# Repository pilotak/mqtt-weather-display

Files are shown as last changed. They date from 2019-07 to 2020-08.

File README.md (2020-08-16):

# MQTT weather display



Simple weather and time display, ready to be controlled from MQTT, based on ESP8266, ILI9341 and DS3231. Icon names are based on clientraw format weather station.

**Custom component from clientraw weather station for HomeAssistant can be found [here](https://github.com/pilotak/homeassistant-clientraw)**

HomeAssistant config:

```yaml
# automations.yaml
- alias: Forecast change
  initial_state: True
  trigger:
    platform: state
    entity_id: sensor.clientraw_symbol
  condition:
    condition: template
    value_template: '{{ trigger.from_state.state != trigger.to_state.state }}'
  action:
    service: mqtt.publish
    data_template:
      topic: "mqtt-weather-display/forecast"
      qos: 1
      retain: true
      payload: >
        {%- set symbol = states.sensor.clientraw_symbol.state -%}
        {%- if symbol is not none and symbol != "unavailable" -%}
          {{ symbol }}
        {%- endif -%}

- alias: Outside temp change
  initial_state: True
  trigger:
    platform: state
    entity_id: sensor.clientraw_temperature
  condition:
    condition: template
    value_template: '{{ trigger.from_state.state != trigger.to_state.state }}'
  action:
    service: mqtt.publish
    data_template:
      topic: "mqtt-weather-display/out-temp"
      qos: 1
      retain: true
      payload: >
        {%- set out_temp = states.sensor.clientraw_temperature.state -%}
        {%- if out_temp is not none and out_temp != "unavailable" -%}
          {{ out_temp }}
        {%- endif -%}

- alias: Inside temp change
  initial_state: True
  trigger:
    platform: state
    entity_id: sensor.myslipotemp_1_0
  condition:
    condition: template
    value_template: '{{ trigger.from_state.state != trigger.to_state.state }}'
  action:
    service: mqtt.publish
    data_template:
      topic: "mqtt-weather-display/in-temp"
      qos: 1
      retain: true
      payload: >
        {%- set in_temp = states.sensor.myslipotemp_1_0.state -%}
        {%- if in_temp is not none and in_temp != "unavailable" -%}
          {{ in_temp }}
        {%- endif -%}

- alias: Outside feel temp change
  initial_state: True
  trigger:
    platform: state
    entity_id: sensor.clientraw_humidex
  condition:
    condition: template
    value_template: '{{ trigger.from_state.state != trigger.to_state.state }}'
  action:
    service: mqtt.publish
    data_template:
      topic: "mqtt-weather-display/out-temp-feel"
      qos: 1
      retain: true
      payload: >
        {%- set out_temp_feel = states.sensor.clientraw_humidex.state -%}
        {%- if out_temp_feel is not none and out_temp_feel != "unavailable" -%}
          {{ out_temp_feel }}
        {%- endif -%}
```

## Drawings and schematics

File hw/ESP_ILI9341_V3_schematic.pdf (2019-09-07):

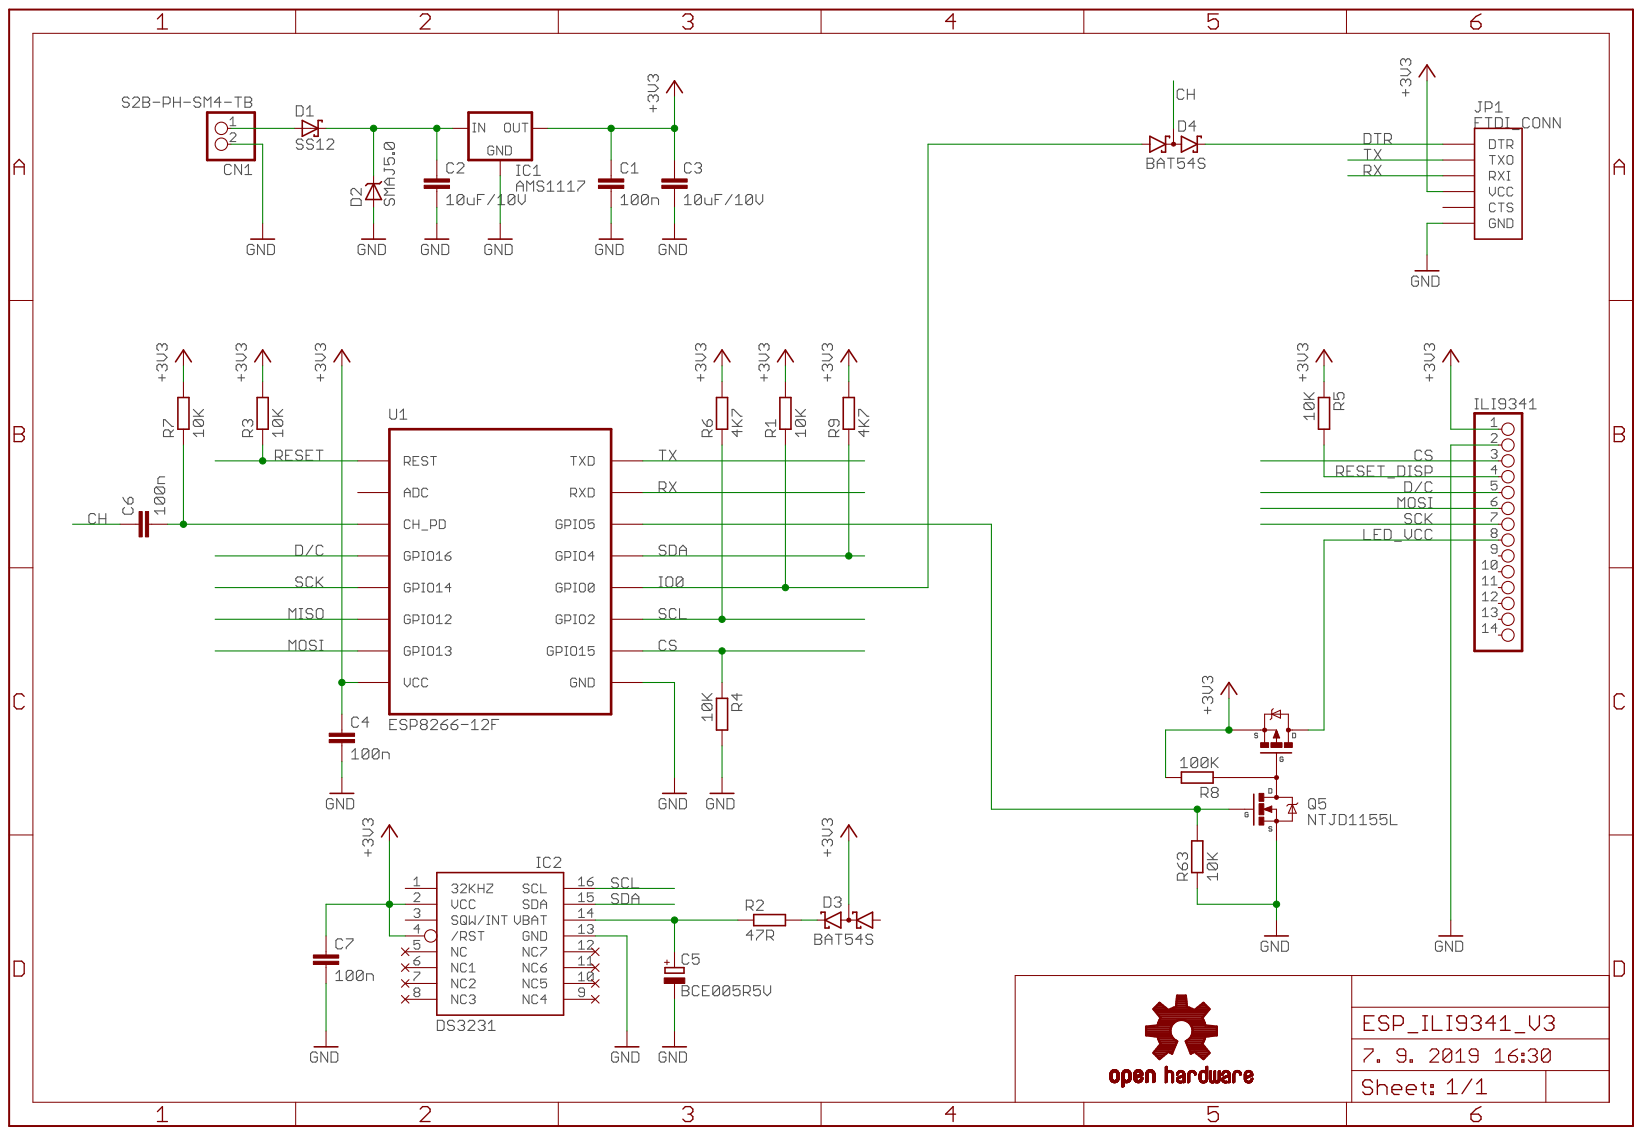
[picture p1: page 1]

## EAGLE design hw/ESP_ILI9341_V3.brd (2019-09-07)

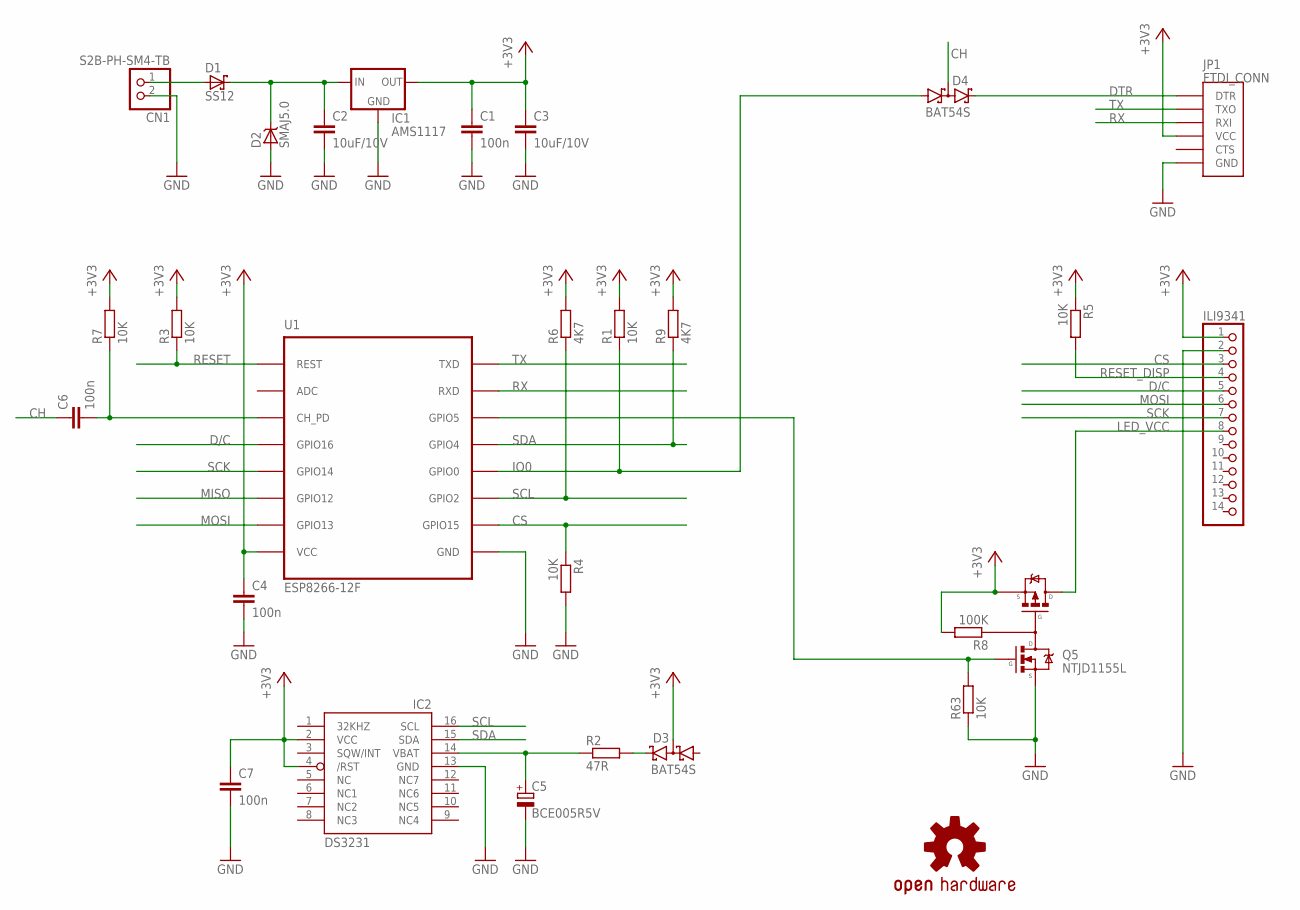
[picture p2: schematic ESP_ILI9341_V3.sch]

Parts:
C1, C4, C6, C7: 100n; C0805
C2, C3: 10uF/10V; C0805
C5: BCE005R5V; BCE
CN1: S2B-PH-SM4-TB; JST-PH-2-SMT-RA
D1: SS12; DO214AC
D2: SMAJ5.0; DO214AC
D3, D4: BAT54S; SOT23
IC1: AMS1117; SOT223
IC2: DS3231/SO; SO16W
ILI9341: PINHD-1X14; 1X14
JP1: FTDI_CONN; FTDI
LOGO1: OSHW-LOGOM-COPPER; OSHW-LOGO-M_COPPER
Q5: NTJD1155L; SOT363
R1, R3, R4, R5, R7, R63: 10K; R0805
R2: 47R; R1206
R6, R9: 4K7; R0805
R8: 100K; R0805
U1: ESP8266-12F; ESP-12

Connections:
+3V3: C1.1, C3.1, C4.1, C7.1, D3.3 (C1A2), IC1.2 (OUT), IC1.4 (OUT), IC2.2 (VCC), IC2.4 (/RST), ILI9341.1, JP1.P$4 (VCC), Q5.4 (S2), R1.2, R3.2, R5.1, R6.2, R7.2, R8.2, R9.2, U1.VCC
CH: C6.1, D4.3 (C1A2)
CS: ILI9341.3, R4.1, U1.GPIO15
D/C: ILI9341.5, U1.GPIO16
DTR: D4.2 (C2), JP1.P$1 (DTR)
GND: C1.2, C2.2, C3.2, C4.2, C5.-, C7.2, CN1.2 (1), D2.A, IC1.1 (GND), IC2.13 (GND), ILI9341.2, JP1.P$6 (GND), Q5.1 (S1), R4.2, R63.1, U1.GND
IO0: D4.1 (A1), R1.1, U1.GPIO0
LED_VCC: ILI9341.8, Q5.2 (D2), Q5.3 (D2)
MISO: U1.GPIO12
MOSI: ILI9341.6, U1.GPIO13
unnamed: D3.2 (C2), R2.2
unnamed: CN1.1 (2), D1.A
unnamed: C2.1, D1.C, D2.C, IC1.3 (IN)
unnamed: C6.2, R7.1, U1.CH_PD
unnamed: C5.+, IC2.14 (VBAT), R2.1
unnamed: Q5.6 (D1/G2), R8.1
unnamed: Q5.5 (G1), R63.2, U1.GPIO5
RESET: R3.1, U1.REST
RESET_DISP: ILI9341.4, R5.2
RX: JP1.P$3 (RXI), U1.RXD
SCK: ILI9341.7, U1.GPIO14
SCL: IC2.16 (SCL), R6.1, U1.GPIO2
SDA: IC2.15 (SDA), R9.1, U1.GPIO4
TX: JP1.P$2 (TXO), U1.TXD

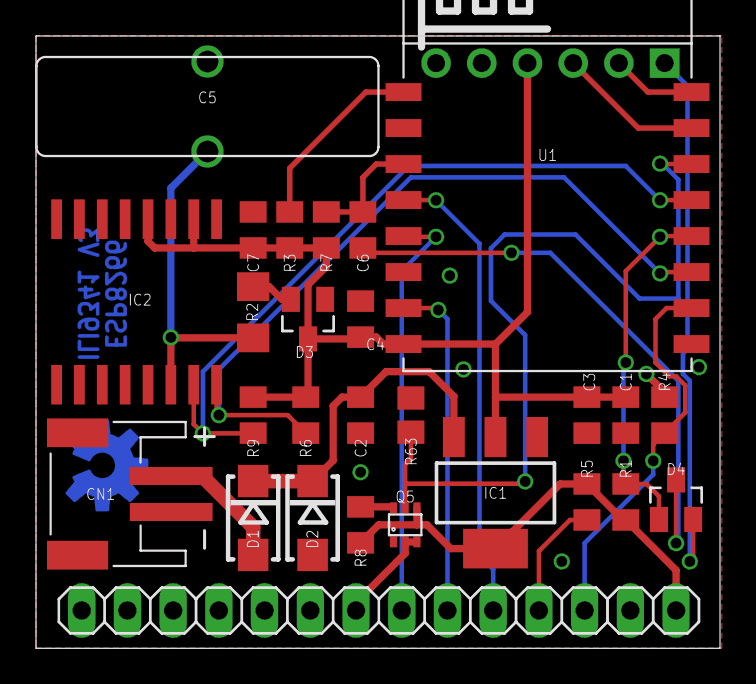
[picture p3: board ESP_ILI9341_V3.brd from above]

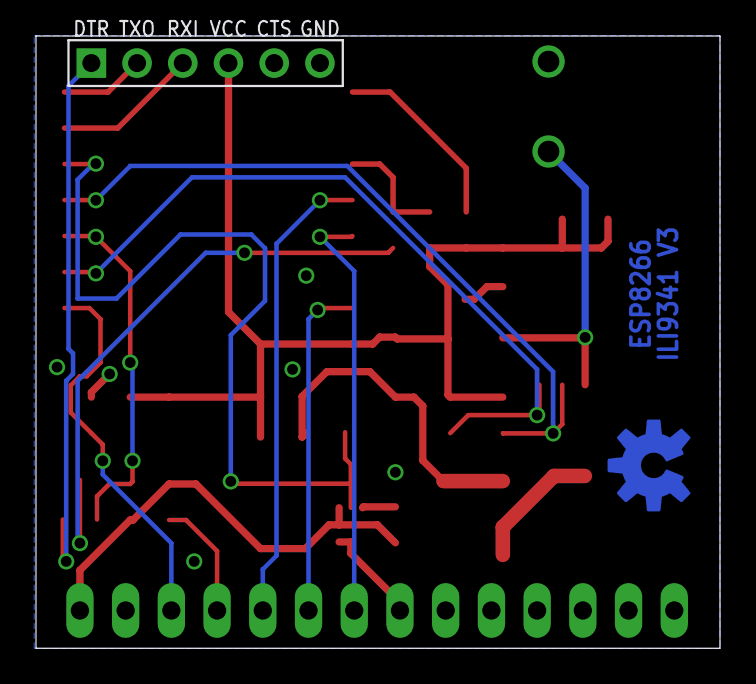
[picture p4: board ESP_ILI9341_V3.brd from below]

Board: 2 copper layers, 38.0 x 34.0 mm, 29 parts (2 on the bottom side), 23 nets.

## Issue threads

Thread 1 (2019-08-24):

cant compile with IDE Arduino

Electronlibre2012, 2019-08-24:
Hello Pilotak,

sorry to bother you, i am relally interesting by your project but i dont suceed to compile your mqtt-weather-display.ino...lots of errors,

which library do you use for ```WifiManager.h``` and ```JC-button.h``` please?

And the TFT you use is I2c?, which one is it please?

I have a SPI one, doesnt work with your sketch i think.

Thanks

Olivier

pilotak, 2019-08-26:
Hi,
it was compiled with PlatformIO but i will try to guide you for Arduino IDE. Below is a list of required libraries:
- https://github.com/bblanchon/ArduinoJson
- https://github.com/tzapu/WiFiManager.git#c3ff582374e677f76d14de013966df0888b5b38e
- https://github.com/marvinroger/async-mqtt-client
- https://github.com/JChristensen/JC_Button
- https://github.com/gmag11/NtpClient
- https://github.com/JChristensen/Timezone
- https://github.com/PaulStoffregen/Time
- https://github.com/adafruit/Adafruit-GFX-Library
- https://github.com/adafruit/Adafruit_ILI9341

Should you need also a DS3231 support https://github.com/JChristensen/DS3232RTC

next is to add macros at the line 20 (just after licence - really important to be a first code) https://github.com/pilotak/mqtt-weather-display/blob/7bc7cd1c3b728c838cd79f5a1a5e3076dacfbea5/MQTT_weather_display/MQTT_weather_display.ino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
```cpp
#define DEBUG
#define ARDUINO_OTA
#define WIFI_MANAGER_MAX_PARAMS=5
#define NTP_SUPPORT
#define HAS_RTC // only if chip is presented
```

Compile and you should be done. As you can see from libs above it uses ILI9341 - SPI display

Electronlibre2012, 2019-08-26:
Hello,

 a big thanks you for your reply! i appreciate that you share your experience! great!

1-I havent a DS3231, so i will buy one right now! but if i understand i can do whithout? just NTP time is ok?
2-If i use a wemos d1 mini is it GPIOs ? :
```
#define SDA_PIN 4
#define SCL_PIN 2
#define TFT_DC  16
#define TFT_CS  15
#define LED_PIN 5
```

I ll try all you explain!
I ll telle you if i suceed ;)

thanks again for all the explanation and the details!

pilotak, 2019-08-27:
ok above libraries have dependencies, you also need
- https://github.com/me-no-dev/ESPAsyncTCP
- https://github.com/me-no-dev/ESPAsyncUDP

no need to `#include`. Just to recap things you need to do:
- install all above libraries
- to line 20 of `MQTT_weather_display.ino` put following (this will shift `#include <limits.h>`)
```cpp
#define DEBUG
#define ARDUINO_OTA
#define WIFI_MANAGER_MAX_PARAMS=5
#define NTP_SUPPORT
#define HAS_RTC // only if chip is presented

#include <limits.h>
#if defined(NTP_SUPPORT) || defined(HAS_RTC)
    #include <Timezone.h>
#endif
...
```
- compile with latest ESP8266 core - `ESP generic 4M (1M SPIFFS)` or` LOLIN(Wemos) D1 R2 & mini  4M (1M SPIFFS)` it doesn't matter
- nothing else (pins are correct)

I have just tried it so i know it works. It would be better for you to install PlatformIO core, you don't have to deal with all of those thing, all you would need is to compile - everything else is done automatically.

I also have a custom made PCB which you just put behind the TFT and you ready to go. I will upload it soon with pictures too.

You don't need the RTC it's just for me to have a time really precise even when without internet. If you want cheaper alternative use DS1307 (not temperature compensated, it would be easy to exchange library). I also use super-capacitor as backup for RTC but you could use coin cell battery too. Of course you don't need it at all, it will be synced with NTP that's why it's splitted into macros which you can comment out. (`NTP_SUPPORT` and `HAS_RTC`)

Just a quick note, you must have N-channel (logic level) and P-channel (logic level, and really important to have low on resistance otherwise backlight will be dimmed) mosfets for LED pin, you must not driver it with GPIO! you can use N&P channel combo https://www.onsemi.com/pub/Collateral/NTJD1155L-D.PDF but it is a small package to solder if you don't mind

Electronlibre2012, 2019-09-05:
Hello,

sorry again, but it doesnt compile....lots of error...i used all the libaries you put .

So i decided to try platformio core but i cant download the " get-platformio.py" ! the website doesnt respond : [https://raw.githubusercontent.com/platformio/platformio/develop/scripts/get-platformio.py](url)

perhaps i try again tomorow...

thanks for your time and help anyway...

pilotak, 2019-09-06:
you can also install with `pip install -U platformio`

pilotak, 2019-09-06:
I also did travis build and that failed due to case sensitive. Could you please try that in case this was the problem. I use Windows where i don't have deal with such a thing

pilotak, 2019-09-07:
Below you can find compiled binaries, you can flash them with [esptool.py](https://nodemcu.readthedocs.io/en/master/flash/)
[mqtt_weather_display.zip](https://github.com/pilotak/mqtt-weather-display/files/3586368/mqtt_weather_display.zip)

Electronlibre2012, 2019-09-07:
Hello @pilotak !

thanks again, i see you make yur best!  its better but an error occur :

```
Using 'COM10' as serial port.
Showing logs:
[15:33:58]rd[15:33:59][FS] mounting...
[15:33:59][FS] mounted
[15:33:59][FS] Reading config file...
[15:33:59][FS] Parsing JSON...
[15:33:59]{
[15:33:59]  "mqtt_server": "192.168.1.100",
[15:33:59]  "mqtt_port": 1883,
[15:33:59]  "mqtt_user": "",
[15:33:59]  "mqtt_password": ""
[15:33:59]}
[15:33:59][FS] JSON parsed
[15:33:59][MQTT] Setup
[15:33:59]*WM: [1] getCoreVersion():          2_5_2
[15:33:59]*WM: [1] system_get_sdk_version():  2.2.1(cfd48f3)
[15:33:59]*WM: [1] system_get_boot_version(): 31
[15:33:59]*WM: [1] getFreeHeap():             43696
[15:33:59]*WM: [3] allocating params bytes: 20
[15:33:59]*WM: [2] Added Parameter: mqtt_server
[15:33:59]*WM: [2] Added Parameter: mqtt_port
[15:33:59]*WM: [2] Added Parameter: mqtt_user
[15:33:59]*WM: [2] Added Parameter: mqtt_password
[15:33:59][WIFI] Connecting to:
[15:33:59]*WM: [1] AutoConnect
[15:33:59]*WM: [2] Setting hostname: mqtt-weather-display
[15:33:59]*WM: [2] Connecting as wifi client...
[15:33:59]*WM: [1] STA static IP:
[15:33:59]*WM: [2] setSTAConfig static ip not set
[15:33:59]*WM: [3] WIFI station disconnect
[15:33:59]*WM: [1] No saved credentials, skipping wifi
[15:33:59]*WM: [2] Connection result: WL_NO_SSID_AVAIL
[15:33:59]*WM: [3] lastconxresult: WL_NO_SSID_AVAIL
```

i have a static ip for my phone on the 192.168.1.100, but i changed i to 101, but the log is identical...

An idea?

pilotak, 2019-09-07:
you need to ground IO0 for at least 1s to bring it to setup mode, this will create wifi AP (for creditals please see `const.h`) once connected with your phone/pc go to web browser, address is http://192.168.4.1 that's where you can setup wifi name, password and MQTT

Electronlibre2012, 2019-09-07:
>
>
> you need to ground IO0 for at least 1s to bring it to setup mode, this will create wifi AP (for creditals please see `const.h`) once connected with your phone/pc go to web browser, address is http://192.168.4.1 that's where you can setup wifi name, password and MQTT

yes sorry..of course...already done this on another weather station from Squix78

Thanks i try!

Electronlibre2012, 2019-09-07:
Great it works! but the screen is white....

```
WiFi station enable
[16:16:53]*WM: [3] enableSTA PERSISTENT ON
[16:16:53]*WM: [1] connectTimeout not set, ESP waitForConnectResult...
[16:16:57][WIFI] Connected
[16:16:57][WIFI] Local IP: 192.168.1.111
[16:16:57][MQTT] Connecting to: 192.168.1.100:1883
[16:16:57]*WM: [2] Connection result: WL_CONNECTED
[16:16:57]*WM: [3] lastconxresult: WL_CONNECTED
[16:16:57]*WM: [1] AutoConnect: SUCCESS
[16:16:57]*WM: [1] STA IP Address: 192.168.1.111
[16:16:57]*WM: [3] hostname: STA mqtt-weather-display
[16:16:59][TIME] Got new NTP time: 14:16:58 07/09/2019
```

pilotak, 2019-09-07:
double check wiring, i have uploaded source files

Electronlibre2012, 2019-09-07:
>
>
> double check wiring, i have uploaded source files
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
pilotak, 2019-09-08:
Wrong mqtt topic should be **mqtt-weather-display/in-temp**

Electronlibre2012, 2019-09-08:
that'it! your the boss!!!

Thanks a lot, now i stop to disturb you!

Thanks again for your time and patience, you are a good person, really!

pilotak, 2019-09-08:
No problem, hope you find this display useful as me.

Electronlibre2012, 2019-09-08:
>
>
> No problem, hope you find this display useful as me.

yes! now i ll try to compile and make some changes if i succeed ;)

Electronlibre2012, 2019-09-08:
Hello,

funny thing i have the code 40 tonight instead of an icon lol

in your code list, its finnish at 35.

Electronlibre2012, 2019-09-08:
Hello,

now its work like a charm but....

my 2 gateway mio xiaomi bug...no responding when the automations are ON....

i dont understand why...i think i will stop this project now...

If you have an idea that what could interfer betwin xiaomi gateway and the mqtt publishing...i will be happy to heard you...

have a good night

pilotak, 2019-09-09:
have you got any devices connected to MQTT other than this display??

Electronlibre2012, 2019-09-09:
no

Le lun. 9 sept. 2019 à 10:24, Pavel S <notifications@github.com> a écrit :

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

Electronlibre2012, 2019-09-09:
i have stop the automations and no more problem...i really dont understand
what the weather station with mqtt do with the xiaomi gateway....

Le lun. 9 sept. 2019 à 10:24, Pavel S <notifications@github.com> a écrit :

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

Electronlibre2012, 2019-09-09:
sorry i have a zigbee dongle zigbee2mqtt but for the moment nothing link.

Electronlibre2012, 2019-09-09:
i saw 2 connections on mqtt : one is the ip 192.168.1.112 is adresse of the
weather station and the other is 172.30.0.2...i dont know exactly what is
it...i read the docker container thing like that....because my mosquitto
server mqtt is on my hassio...

Le lun. 9 sept. 2019 à 10:24, Pavel S <notifications@github.com> a écrit :

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

pilotak, 2019-09-09:
try create another login to Mosquitto so that dongle has it's own and display has it's own there could a collision. This is more likely problem with HA not with display i have 10 devices connected to MQTT with no problem and same credentials. Have tried to unplug the dongle?

pilotak, 2019-09-09:
also set password for new login in case you don't have it. Don't forget to ground IO0 to change mqtt setting

pilotak, 2019-09-09:
also try `sudo systemctl stop zigbee2mqtt`

Electronlibre2012, 2019-09-09:
ok thanks! yes i think also it s more a Ha problem...

i ll try when i ll be back home,

have a nice day

Le lun. 9 sept. 2019 à 11:43, Pavel S <notifications@github.com> a écrit :

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

Electronlibre2012, 2019-09-09:
hello,

i found a way to make it work : i create an automation in "config" "automation" with the UI.
Then an "id" number is attribuate to the automation and i complete the automation in "configurator" tool.
It works.
Seems it slower my gateways functions and continue to generate errors like:
```
2019-09-09 21:37:52 ERROR (SyncWorker_13) [xiaomi_gateway] No data in response from hub None
2019-09-09 21:37:54 ERROR (SyncWorker_5) [xiaomi_gateway] Cannot connect to Gateway
```
but it seems to doesnt crash my gateways...

Strange...

Any idea please?

here is the automation that "works" :
```
- id: '1568050232806'
  alias: in temp changed
  trigger:
  - entity_id: sensor.temperature_158d000349c288
    platform: state
  condition:
  - condition: template
    value_template: '"{{ trigger.from_state.state != trigger.to_state.state }}"'
  action:
  - service: mqtt.publish
    data_template:
      topic: mqtt-weather-display/in-temp
      qos: 1
      retain: true
      payload: >
        {%- set in_temp = states.sensor.temperature_158d000349c288.state -%}
        {%- if in_temp is not none and in_temp != "unavailable" -%}
          {{ in_temp }}
        {%- endif -%}
```

pilotak, 2019-09-11:
Don't know really, you should be taking it further with the gateway, because it's silly not to have automations and MQTT together

Closed 2019-09-08.

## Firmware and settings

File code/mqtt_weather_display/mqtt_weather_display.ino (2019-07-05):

/*
MIT License
Copyright (c) 2019 Pavel Slama
Permission is hereby granted, free of charge, to any person obtaining a copy
of this software and associated documentation files (the "Software"), to deal
in the Software without restriction, including without limitation the rights
to use, copy, modify, merge, publish, distribute, sublicense, and/or sell
copies of the Software, and to permit persons to whom the Software is
furnished to do so, subject to the following conditions:
The above copyright notice and this permission notice shall be included in all
copies or substantial portions of the Software.
THE SOFTWARE IS PROVIDED "AS IS", WITHOUT WARRANTY OF ANY KIND, EXPRESS OR
IMPLIED, INCLUDING BUT NOT LIMITED TO THE WARRANTIES OF MERCHANTABILITY,
FITNESS FOR A PARTICULAR PURPOSE AND NONINFRINGEMENT. IN NO EVENT SHALL THE
AUTHORS OR COPYRIGHT HOLDERS BE LIABLE FOR ANY CLAIM, DAMAGES OR OTHER
LIABILITY, WHETHER IN AN ACTION OF CONTRACT, TORT OR OTHERWISE, ARISING FROM,
OUT OF OR IN CONNECTION WITH THE SOFTWARE OR THE USE OR OTHER DEALINGS IN THE
SOFTWARE.
*/
#include <limits.h>
#if defined(NTP_SUPPORT) || defined(HAS_RTC)
    #include <Timezone.h>
#endif

#include "const.h"
#include "load.h"
#include "wifi.h"
#include "mqtt.h"
#include "ota.h"
#include "button.h"

#if defined(NTP_SUPPORT) || defined(HAS_RTC)
    #include "clock.h"
#endif

#include "display.h"

void setup() {
#if defined(DEBUG) || defined(DEBUG_ESP_PORT)
    Serial.begin(115200);
    Serial.println();
#endif

    setupDisplay();

    if (loadDefaultConfig()) {
        buttonSetup();

#if defined(NTP_SUPPORT) || defined(HAS_RTC)
        setupTime();
#endif
        mqttSetup();
        wifiSetup();
        otaSetup();

    } else {
        while (1) {};
    }
}

void loop() {
    otaLoop();

    if (!ota_in_progess) {
        wifiManager.process();
        buttonLoop();
        displayLoop();

        if (WiFi.isConnected()) {
            mqttLoop();
#if defined(NTP_SUPPORT) || defined(HAS_RTC)
            timeLoop();
#endif
        }
    }

#if defined(HTTP_OTA)

    if (do_http_update) {
        do_http_update = false;
        httpUpdate();
    }

#endif
}

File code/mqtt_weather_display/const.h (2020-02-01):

#define DEVICE_NAME "mqtt-weather-display"  // used for MQTT, OTA, AP
#define FW_VERSION "1.0.1"

#define CONFIG_PATH               "/config.json"
#define CONFIG_AP_SSID            DEVICE_NAME "-config"
#define CONFIG_AP_PASSWORD        "StrongPasswordHere"
#define CONFIG_PORTAL_TIMEOUT     120  // sec

#define DEFAULT_MQTT_PORT         1883
#define MQTT_QOS                  1
#define MQTT_RETAIN               true
#define MQTT_CHECK_INTERVAL       5000
#define MQTT_STATUS_INTERVAL      30000
#define MQTT_STATUS_TOPIC         DEVICE_NAME "/status"
#define MQTT_UPGRADE_TOPIC        DEVICE_NAME "/upgrade"
#define MQTT_UPGRADE_STATUS_TOPIC DEVICE_NAME "/upgrade/status"
#define MQTT_RESTART_TOPIC        DEVICE_NAME "/restart"
#define MQTT_NTP_TOPIC            DEVICE_NAME "/ntp"

#define MQTT_TOPIC_IN_TEMP        DEVICE_NAME "/in-temp"
#define MQTT_TOPIC_OUT_TEMP       DEVICE_NAME "/out-temp"
#define MQTT_TOPIC_OUT_TEMP_FEEL  DEVICE_NAME "/out-temp-feel"
#define MQTT_TOPIC_FORECAST       DEVICE_NAME "/forecast"
#define MQTT_TOPIC_POWER          DEVICE_NAME "/power"
#define MQTT_TOPIC_NIGHT_MODE     DEVICE_NAME "/night"

#define MQTT_STATUS_ALIVE 1
#define MQTT_STATUS_DEAD 0

#define BUTTON_PIN 0
#define LONG_PRESS 1000  // ms

#define NOFUSS_CHECK_INTERVAL 3600000  // 1h
#define OTA_PORT              8266  // for local updates

#if defined(NTP_SUPPORT) || defined(HAS_RTC)
#if defined(HAS_RTC)
#define TIME_SYNC_INTERVAL 180  // sec
#define NTP_TIME_RESYNC    24  // this * TIME_SYNC_INTERVAL = resync time
#else
#define TIME_SYNC_INTERVAL 600  // sec; NTP should not be that often
#endif

#define NTP_SERVER_NAME    "pool.ntp.org"

TimeChangeRule summerTime   = {"CEST", Last, Sun, Mar, 2, 120};    // UTC + 2 hours
TimeChangeRule standardTime = {"CET", Last, Sun, Oct, 2, 60};    // UTC + 1 hour
#endif

#define SDA_PIN 4
#define SCL_PIN 2
#define TFT_DC  16
#define TFT_CS  15
#define LED_PIN 5

const uint16_t background_colour = 0x0000;
const uint16_t font_colour       = 0xFFFF;

#define IN_TEMP_POS_Y       315
#define OUT_TEMP_POS_Y      63
#define OUT_TEMP_FEEL_POS_Y 89
#define POWER_POS_Y         IN_TEMP_POS_Y

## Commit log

2017-05-17 pin update
2019-09-06 case test2
2019-09-06 case sensitive
2019-09-07 eagle files
    [ESP_ILI9341_V3.brd, ESP_ILI9341_V3.sch]
2020-02-01 bug fix MQTT lib
    [load.h]
2020-08-16 folder restructure
    [ESP_ILI9341_V3.brd, ESP_ILI9341_V3.sch]
2020-08-16 move schematic under hw

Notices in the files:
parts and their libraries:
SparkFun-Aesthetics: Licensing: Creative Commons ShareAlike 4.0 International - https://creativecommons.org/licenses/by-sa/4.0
